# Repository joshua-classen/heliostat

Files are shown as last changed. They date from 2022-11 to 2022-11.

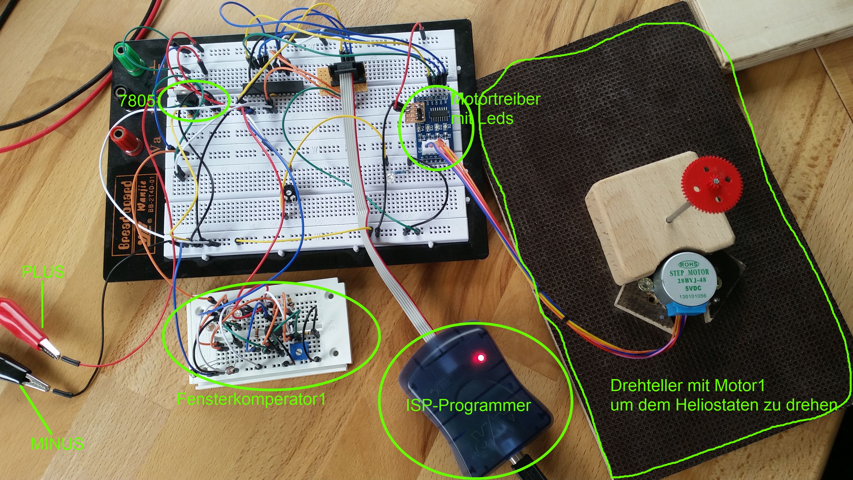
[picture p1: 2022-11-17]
bilder/Testboard/Testboard.jpeg

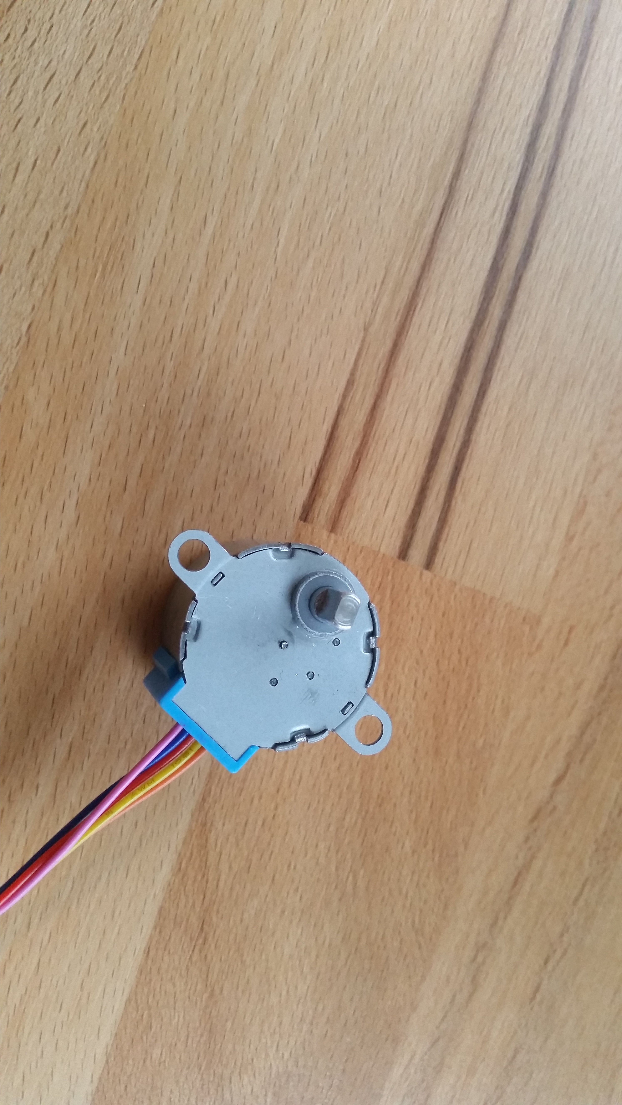
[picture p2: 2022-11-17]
bilder/motor/20150522_195113.jpg

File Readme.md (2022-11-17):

Sun Follower | heliostat

This repo contains code for my heliostat robot which is able to align itself to a light source.

The heliostat in action can be viewed on youtube:

IMAGE ALT TEXT HERE (https://www.youtube.com/watch?v=elJdgMtm6Kk)

I developed and built the heliostat in year 2015
Years ago I uploaded the files to bitbucket: https://bitbucket.org/ckrex/myheliostatcontrol/src/master/

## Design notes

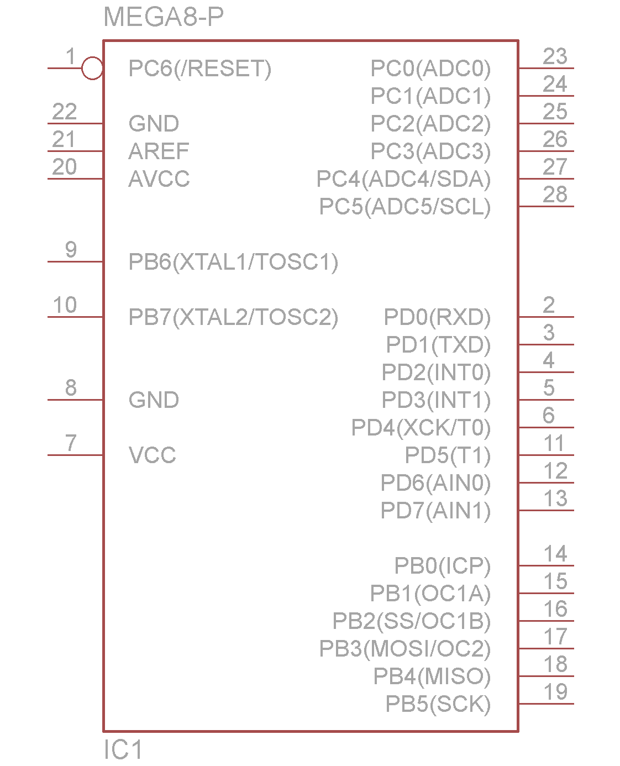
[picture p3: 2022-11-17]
eagle/heliostat/atmega8risc.png

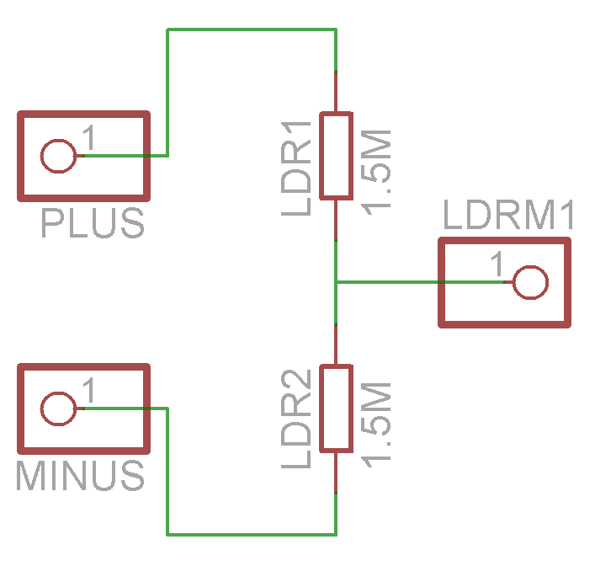
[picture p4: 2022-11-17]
eagle/heliostat/LDRM1.png

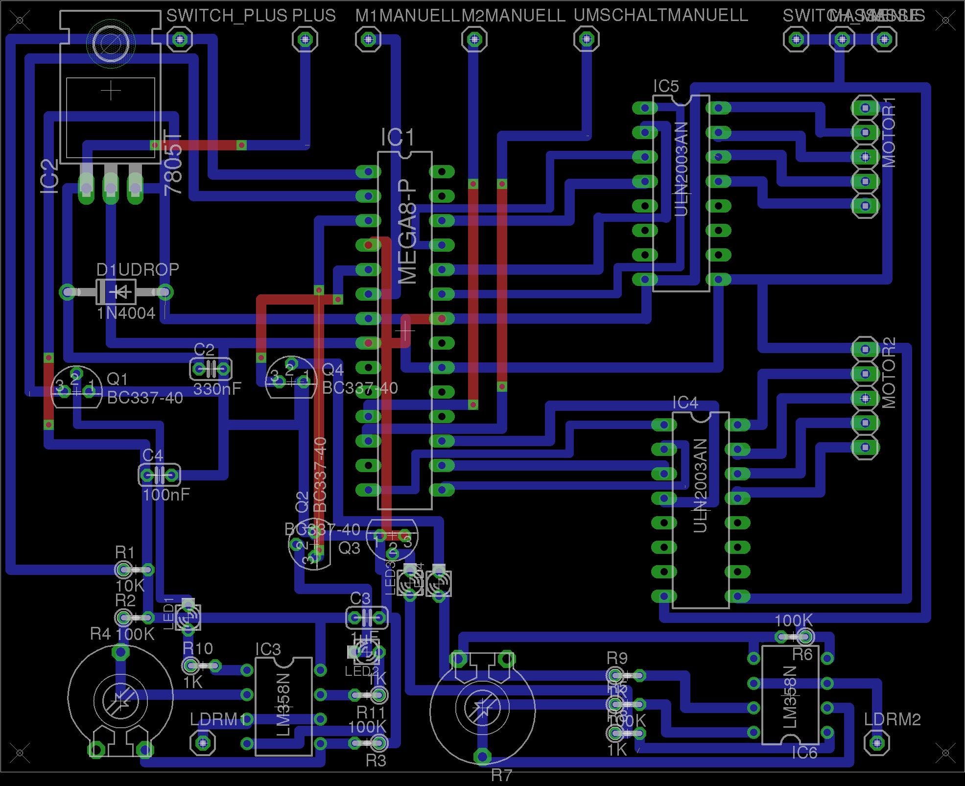
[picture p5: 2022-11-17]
eagle/heliostat/Board.png

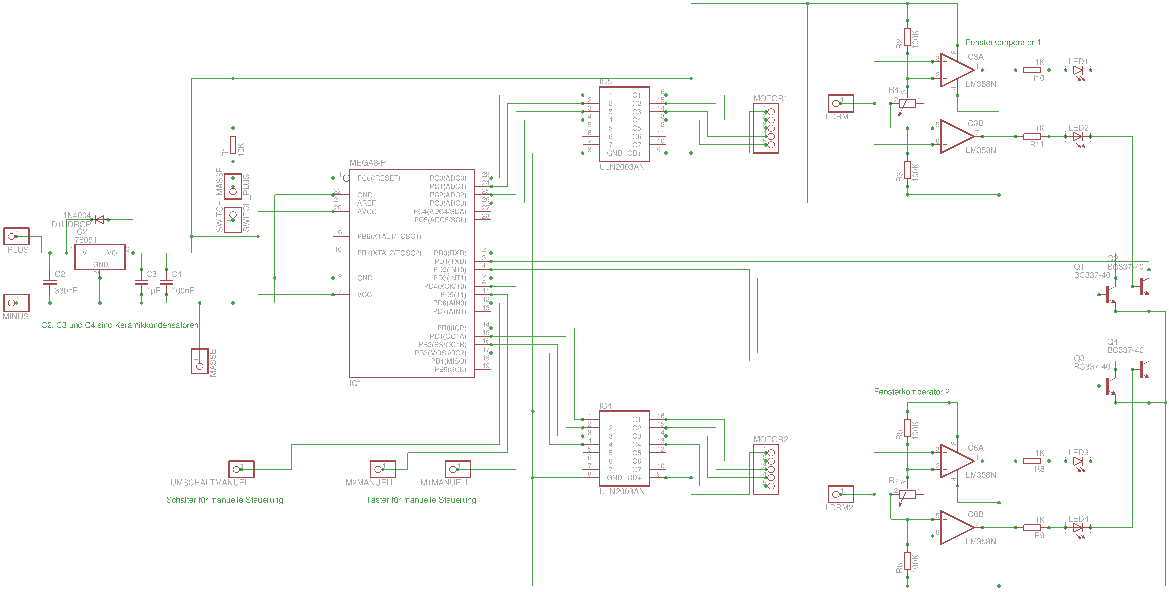
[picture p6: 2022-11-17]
eagle/heliostat/Schaltplanheliostat_neu.png

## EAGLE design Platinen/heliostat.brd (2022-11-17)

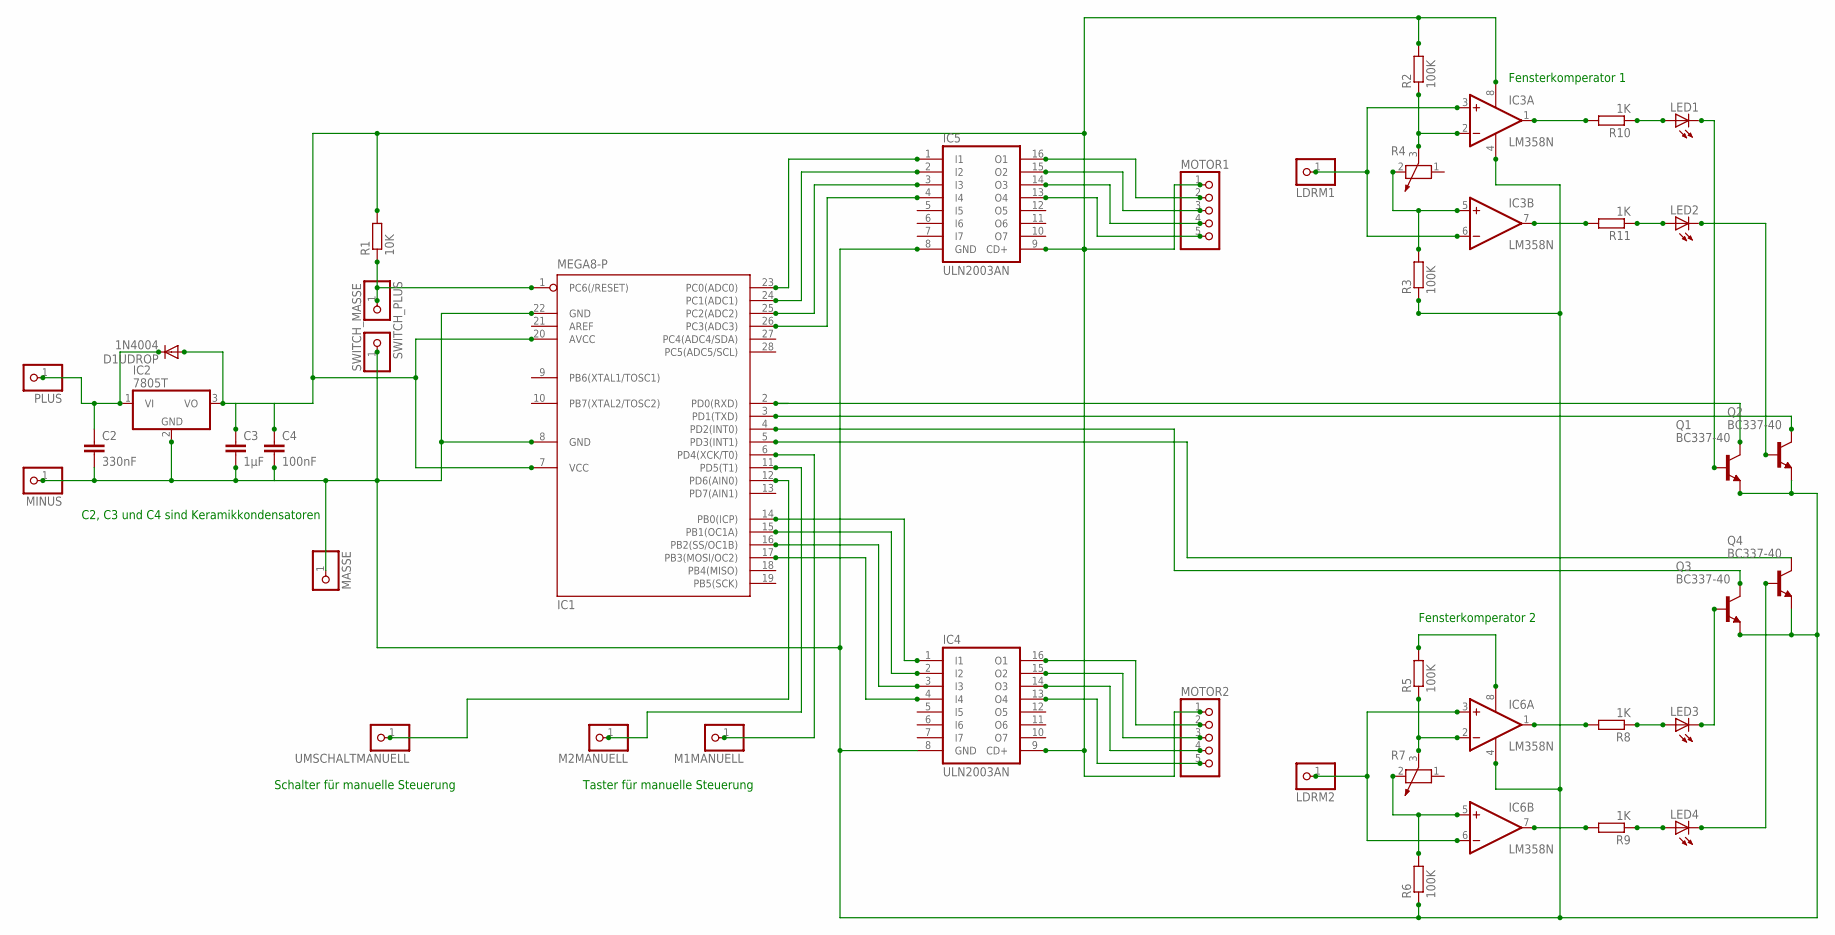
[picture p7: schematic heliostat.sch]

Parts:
C2: 330nF; C025-024X044
C3: 1µF; C025-024X044
C4: 100nF; C025-024X044
D1UDROP: 1N4004; DO41-10
IC1: MEGA8-P; DIL28-3
IC2: 7805T; TO220H
IC3, IC6: LM358N; DIL08
IC4, IC5: ULN2003AN; DIL16
LDRM1, LDRM2: PINHD-1X1; 1X01
LED1, LED2, LED3, LED4: LED_ELD260; LED_LD260
M1MANUELL, M2MANUELL: PINHD-1X1; 1X01
MASSE: PINHD-1X1; 1X01
MINUS: PINHD-1X1; 1X01
MOTOR1, MOTOR2: PINHD-1X5; 1X05
PLUS: PINHD-1X1; 1X01
Q1, Q2, Q3, Q4: BC337-40; TO92
R1: 10K; 0204V
R2, R3, R5, R6: 100K; 0204V
R4, R7: POTENTIOMETER_PT-10; PT-10
R8, R9, R10, R11: 1K; 0204V
SWITCH_MASSE: PINHD-1X1; 1X01
SWITCH_PLUS: PINHD-1X1; 1X01
UMSCHALTMANUELL: PINHD-1X1; 1X01

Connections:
unnamed: IC1.23 (PC0(ADC0)), IC5.1 (I1)
unnamed: IC3.2 (-IN), R2.1, R4.3
unnamed: IC1.24 (PC1(ADC1)), IC5.2 (I2)
unnamed: C2.1, D1UDROP.C, IC2.1 (VI), PLUS.1
unnamed: IC1.2 (PD0(RXD)), Q1.3 (C)
unnamed: IC1.25 (PC2(ADC2)), IC5.3 (I3)
unnamed: IC1.26 (PC3(ADC3)), IC5.4 (I4)
unnamed: IC5.16 (O1), MOTOR1.2
unnamed: IC5.15 (O2), MOTOR1.3
unnamed: IC5.14 (O3), MOTOR1.4
unnamed: IC5.13 (O4), MOTOR1.5
unnamed: IC1.14 (PB0(ICP)), IC4.1 (I1)
unnamed: IC1.15 (PB1(OC1A)), IC4.2 (I2)
unnamed: IC1.16 (PB2(SS/OC1B)), IC4.3 (I3)
unnamed: IC1.17 (PB3(MOSI/OC2)), IC4.4 (I4)
unnamed: IC4.16 (O1), MOTOR2.2
unnamed: IC4.15 (O2), MOTOR2.3
unnamed: IC4.14 (O3), MOTOR2.4
unnamed: IC4.13 (O4), MOTOR2.5
unnamed: C3.1, C4.1, D1UDROP.A, IC1.7 (VCC), IC1.20 (AVCC), IC2.3 (VO), IC3.8 (V+), IC4.9 (CD+), IC5.9 (CD+), MOTOR1.1, MOTOR2.1, R1.2, R2.2
unnamed: IC3.5 (+IN), R3.2, R4.2
unnamed: IC6.8 (V+), R5.2
unnamed: IC3.3 (+IN), IC3.6 (-IN), LDRM1.1
unnamed: IC6.1 (OUT), R8.2
unnamed: IC6.2 (-IN), R5.1, R7.3
unnamed: IC6.5 (+IN), R6.2, R7.2
unnamed: IC6.3 (+IN), IC6.6 (-IN), LDRM2.1
unnamed: LED3.A, R8.1
unnamed: IC6.7 (OUT), R9.2
unnamed: LED4.A, R9.1
unnamed: IC3.7 (OUT), R11.2
unnamed: LED2.A, R11.1
unnamed: IC3.1 (OUT), R10.2
unnamed: LED1.A, R10.1
unnamed: IC1.1 (PC6(/RESET)), R1.1, SWITCH_PLUS.1
unnamed: IC1.6 (PD4(XCK/T0)), M1MANUELL.1
unnamed: LED1.K (C), Q1.2 (B)
unnamed: LED2.K (C), Q2.2 (B)
unnamed: IC1.3 (PD1(TXD)), Q2.3 (C)
unnamed: LED3.K (C), Q3.2 (B)
unnamed: IC1.4 (PD2(INT0)), Q3.3 (C)
unnamed: LED4.K (C), Q4.2 (B)
unnamed: IC1.5 (PD3(INT1)), Q4.3 (C)
unnamed: IC1.11 (PD5(T1)), M2MANUELL.1
unnamed: C2.2, C3.2, C4.2, IC1.8 (GND), IC1.22 (GND), IC2.2 (GND), IC3.4 (V-), IC4.8 (GND), IC5.8 (GND), IC6.4 (V-), MASSE.1, MINUS.1, Q1.1 (E), Q2.1 (E), Q3.1 (E), Q4.1 (E), R3.1, R6.1, SWITCH_MASSE.1
unnamed: IC1.12 (PD6(AIN0)), UMSCHALTMANUELL.1

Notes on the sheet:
C2, C3 und C4 sind Keramikkondensatoren
Fensterkomperator 1
Fensterkomperator 2
Taster für manuelle Steuerung
Schalter für manuelle Steuerung

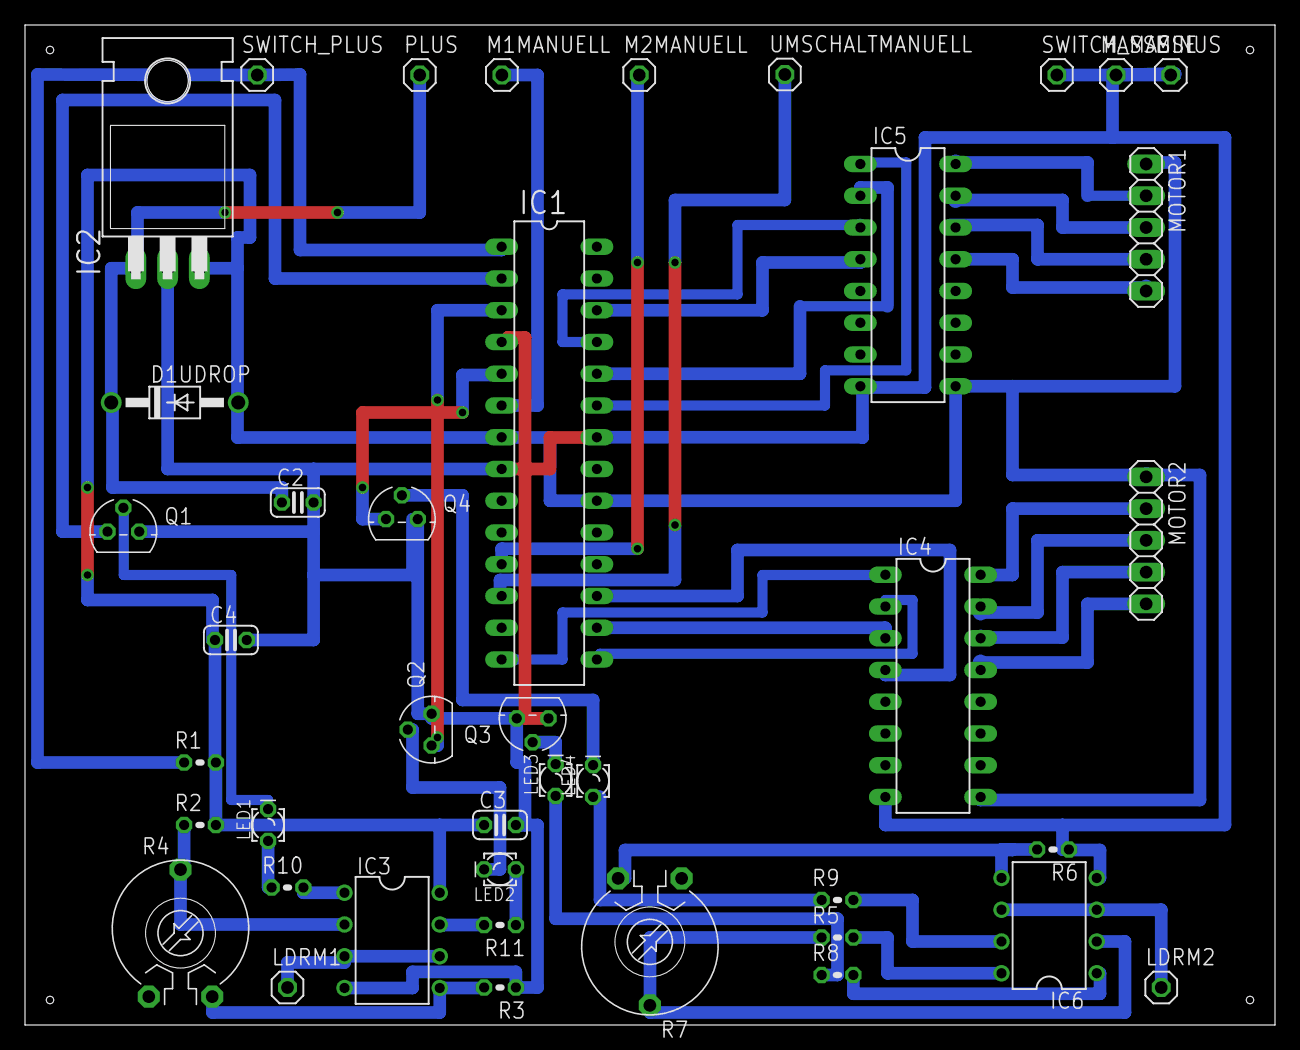
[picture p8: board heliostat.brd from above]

Board: 2 copper layers, 100.0 x 80.0 mm, 41 parts (0 on the bottom side), 46 nets.

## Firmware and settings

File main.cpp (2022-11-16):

/*
 * main.cpp
 *
 * Created: 10.05.2015 17:00:43
 *  Author: Joshua Classen
 */
//Die Dokumentation zu den Funktionen finden Sie in den Header (.hpp) Dateien
#define F_CPU 8000000UL       //Taktfrequenz 8MHz
//#define F_CPU 1000000UL
#include <avr/io.h>
#include <util/delay.h>

#include "motor.hpp"
#include "global.hpp"


//motor1

#define MOTOR1_PIN0  PC0
#define MOTOR1_PIN1  PC1
#define MOTOR1_PIN2  PC2
#define MOTOR1_PIN3  PC3


//motor2
#define MOTOR2_PIN0 PB0
#define MOTOR2_PIN1 PB1
#define MOTOR2_PIN2 PB2
#define MOTOR2_PIN3 PB3




#define TASTER_M1_MANUELL PD4
#define TASTER_M2_MANUELL PD5
#define TASTER_UMSCHALT_MANUELL PD6



/*

INFO:
step motor 28byj-48
Schrittmotor benötigt 2048 steps für 360°

*/
// .equ	DDRB	=$17

static bool manualcontroll = false; //manuelle Kontrolle über Taster standardmäßig nicht aktiviert.
static bool warmanualcontrollvorheraktiviert = false;




int main(void)
{
    init_atmega(); //ports initialisieren

    motor motorRollall(MOTOR1_PIN0, MOTOR1_PIN1, MOTOR1_PIN2, MOTOR1_PIN3, &PORTC);
    motor motorRollSolarpanele(MOTOR2_PIN0, MOTOR2_PIN1, MOTOR2_PIN2, MOTOR2_PIN3, &PORTB);




    while(true)
    {
		//Tasterabfrage
        if ( !(PIND & (1<<TASTER_UMSCHALT_MANUELL)) ) //wenn bit gesetz ist (pull up widerstände) // Wenn Taster gedrückt
		{
            if(warmanualcontrollvorheraktiviert == false)
            {
                manualcontroll = true;
            }
            else
            {
                manualcontroll = false;
            }
			//abfragen ob Taster vorher schon aktiviert wurde

		}

		if ( PIND & (1<<TASTER_UMSCHALT_MANUELL) ) //wenn bit nicht gesetz ist (pull up widerstände) // Wenn Taster nicht gedrückt
		{
            if(manualcontroll == true) // manualcontroll ist noch an
            {
                warmanualcontrollvorheraktiviert = true; //manualcontroll war vorher an

            }
            else //manualcontroll == false
            {
                warmanualcontrollvorheraktiviert = false;
            }
		}



		if(manualcontroll == false) //wenn manuelle Kontrolle nicht aktiviert ist, dann fürhre automatische Steuerung aus
		{

			//MOTOR1
			if ( !(PIND & (1<<PIND0)) ) //wenn bit gesetz ist (pull up widerstände)
			{
				motorRollall.rechtsrum(10,1);
			}


			if ( !(PIND & (1<<PIND1)) ) //wenn bit gesetz ist (pull up widerstände)
			{
				motorRollall.linksrum(10,1);
			}




			//MOTOR2
			if ( !(PIND & (1<<PIND2)) ) //wenn bit gesetz ist (pull up widerstände)
			{
				motorRollSolarpanele.linksrum(10,1);
			}


			if ( !(PIND & (1<<PIND3)) ) //wenn bit gesetz ist (pull up widerstände)
			{
				motorRollSolarpanele.rechtsrum(10,1);
			}

		}


		if(manualcontroll == true) //wenn manuelle Ḱontrolle aktiviert ist
		{
            if ( !(PIND & (1<<TASTER_M1_MANUELL)) ) //wenn bit gesetz ist (pull up widerstände)
            {
                motorRollall.linksrum(10,1);
            }

            if ( !(PIND & (1<<TASTER_M2_MANUELL)) ) //wenn bit gesetz ist (pull up widerstände)
            {
                motorRollSolarpanele.linksrum(10,1);
            }
		}
    }


}

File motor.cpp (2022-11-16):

/*
 * motor.cpp
 *
 * Created: 10.05.2015 17:00:43
 *  Author: Joshua Classen
 */

//Die Dokumentation zu den Funktionen finden Sie in den Header (.hpp) Dateien
#include "motor.hpp"




motor::motor(const uint8_t &pin0_ = 0, const uint8_t &pin1_ = 0, const uint8_t &pin2_ = 0, const uint8_t &pin3_ = 0, volatile uint8_t *port_of_motor = 0):
                                                                                pin0(pin0_), pin1(pin1_), pin2(pin2_), pin3(pin3_), port_motor(port_of_motor) {}







void motor::setPin(const unsigned &pin_num ,const bool &status)
{
	if(status) //if high
	{
		//sezte bit pin_num auf high.
        *port_motor |= (1<<pin_num);
	}

	else
	{
		//setze bit pin_num auf low.
		*port_motor &= ~(1<<pin_num);
	}
}








void motor::stop(void)
{
	setPin(pin0, LOW);
	setPin(pin1, LOW);
	setPin(pin2, LOW);
	setPin(pin3, LOW);
}


void motor::rechtsrum(unsigned motorspeed, const double &degree)
{
	/*	Der Schrittmotor benötigt 512 Schritte für eine volle Umdrehung.
		Deshalb rechnet man 512 / 360 = 1.42222222222
	*/


	if(motorspeed == 0) ++motorspeed; //Motor darf keine unendliche Geschwindigkeit haben



	for(unsigned ix = 0; ix < degree*1.4222222; ++ix)
	{
		//1
		setPin(pin0, HIGH);
		setPin(pin1, LOW);
		setPin(pin2, LOW);
		setPin(pin3, LOW);

		wait_ms(motorspeed);

		//2
		setPin(pin0, HIGH);
		setPin(pin1, HIGH);
		setPin(pin2, LOW);
		setPin(pin3, LOW);

		wait_ms(motorspeed);

		//3
		setPin(pin0, LOW);
		setPin(pin1, HIGH);
		setPin(pin2, LOW);
		setPin(pin3, LOW);

		wait_ms(motorspeed);

		//4
		setPin(pin0, LOW);
		setPin(pin1, HIGH);
		setPin(pin2, HIGH);
		setPin(pin3, LOW);

		wait_ms(motorspeed);

		//5
		setPin(pin0, LOW);
		setPin(pin1, LOW);
		setPin(pin2, HIGH);
		setPin(pin3, LOW);

		wait_ms(motorspeed);

		//6
		setPin(pin0, LOW);
		setPin(pin1, LOW);
		setPin(pin2, HIGH);
		setPin(pin3, HIGH);

		wait_ms(motorspeed);

		//7
		setPin(pin0, LOW);
		setPin(pin1, LOW);
		setPin(pin2, LOW);
		setPin(pin3, HIGH);

		wait_ms(motorspeed);

		//8
		setPin(pin0, HIGH);
		setPin(pin1, LOW);
		setPin(pin2, LOW);
		setPin(pin3, HIGH);

		wait_ms(motorspeed);
	}
	stop();
}



void motor::linksrum(unsigned motorspeed, const double &degree)
{
	/*	Der Schrittmotor benötigt 512 Schritte für eine volle Umdrehung.
		Deshalb rechnet man 512 / 360 = 1.42222222222
	*/

	if(motorspeed == 0) ++motorspeed; //Motor darf keine unendliche Geschwindigkeit haben, darum wird Wert auf 1 gesetzt falls er auf 0 stehen sollte.

	for(unsigned ix = 0; ix < degree*1.42222222; ++ix)
	{
		//8
		setPin(pin0, HIGH);
		setPin(pin1, LOW);
		setPin(pin2, LOW);
		setPin(pin3, HIGH);

		wait_ms(motorspeed);

		//7
		setPin(pin0, LOW);
		setPin(pin1, LOW);
		setPin(pin2, LOW);
		setPin(pin3, HIGH);

		wait_ms(motorspeed);

		//6
		setPin(pin0, LOW);
		setPin(pin1, LOW);
		setPin(pin2, HIGH);
		setPin(pin3, HIGH);

		wait_ms(motorspeed);

		//5
		setPin(pin0, LOW);
		setPin(pin1, LOW);
		setPin(pin2, HIGH);
		setPin(pin3, LOW);

		wait_ms(motorspeed);

		//4
		setPin(pin0, LOW);
		setPin(pin1, HIGH);
		setPin(pin2, HIGH);
		setPin(pin3, LOW);

		wait_ms(motorspeed);

		//3
		setPin(pin0, LOW);
		setPin(pin1, HIGH);
		setPin(pin2, LOW);
		setPin(pin3, LOW);

		wait_ms(motorspeed);

		//2
		setPin(pin0, HIGH);
		setPin(pin1, HIGH);
		setPin(pin2, LOW);
		setPin(pin3, LOW);

		wait_ms(motorspeed);

		//1
		setPin(pin0, HIGH);
		setPin(pin1, LOW);
		setPin(pin2, LOW);
		setPin(pin3, LOW);

		wait_ms(motorspeed);
	}
	stop();
}
